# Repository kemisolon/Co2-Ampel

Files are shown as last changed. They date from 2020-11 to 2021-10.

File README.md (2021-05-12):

# Co2-Ampel
GitHub Logo

## ZTL (Zentrum für Technikkultur Landau) 
*** 

## Hardware:
1x Arduino Nano
5x WS2812B
1x SCD30

## Grenzwerte für die Co2-Ampel
grün  400-700ppm
gelb  700-1000ppm
rot   1000-2000ppm
rot-blinkend >2000ppm

## Gehäuse
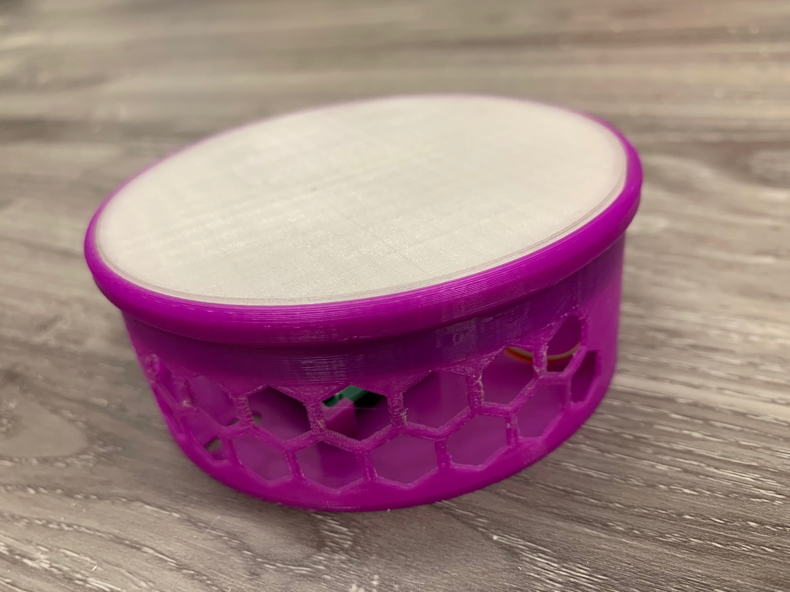
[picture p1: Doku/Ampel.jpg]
Die Ampel

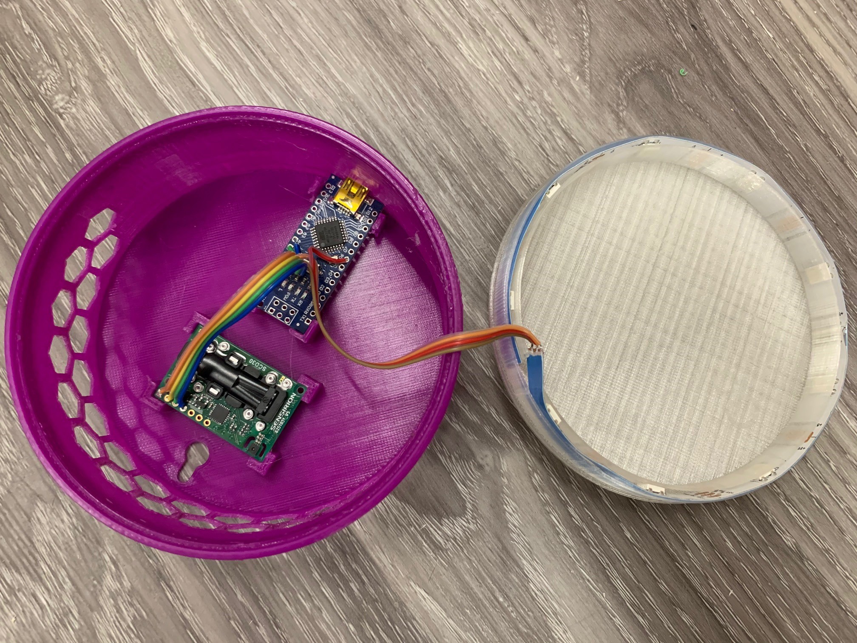
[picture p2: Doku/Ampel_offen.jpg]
Die Ampel offen


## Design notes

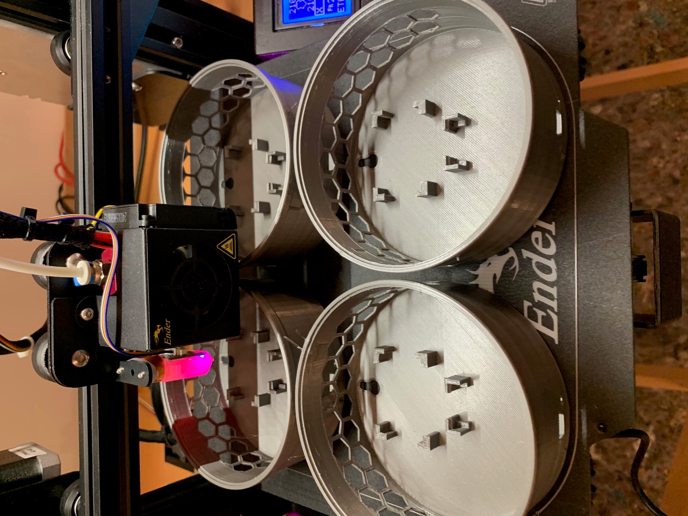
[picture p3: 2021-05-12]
Doku/druck.jpg

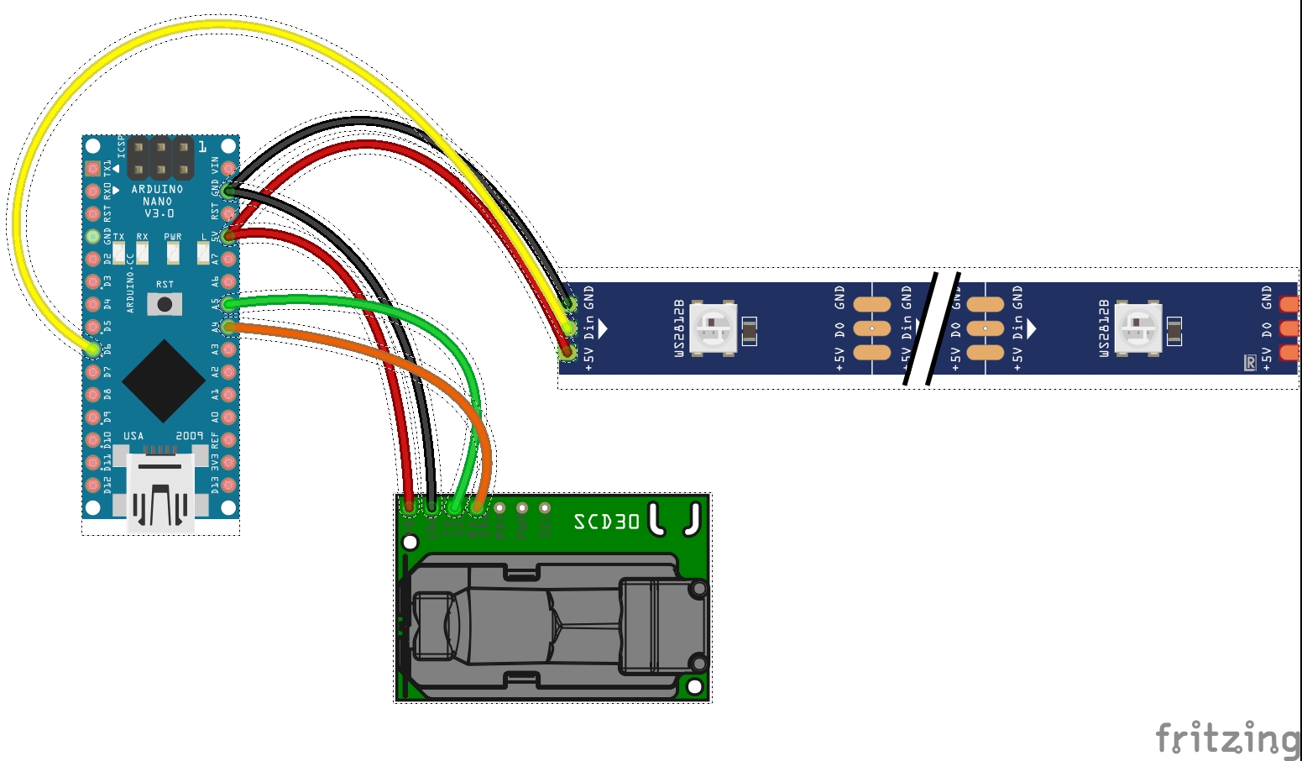
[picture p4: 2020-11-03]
Schaltplan/Schaltplan_Steckplatine.jpg

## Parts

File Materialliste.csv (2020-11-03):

Name | Quelle | Anzahl | Link
Arduino Nano | Amazon | 1/3 | https://www.amazon.de/AZDelivery-Atmega328-gratis-Arduino-kompatibel/dp/B078SBBST6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
CO2-Sensor SCD30 | Mouser | 1/100 | https://www.mouser.de/ProductDetail/403-SCD30SAMPLEEXT
LED WS2812B | Amazon | 1/100 | https://www.amazon.de/CHINLY-adressierbaren-LED-Streifen-Traumfarbe-Wasserdichte/dp/B07TKHMMZ2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
510 Ohm Widerstand | Reichelt | 1 | https://www.reichelt.de/widerstand-metallschicht-510-ohm-0207-0-6-w-1--metall-510-p11862.html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
MINI-USB-Kabel 2m Länge | Amazon | 1 | https://www.amazon.de/Premium-Cord-Kabel-B-Mini-5pins/dp/B00I97P5NI?__mk_de_DE=%C3%85M%C3%85%C5%BD%C3%95%C3%91
USB-Netzeil | Amazon | 1/100 | https://www.amazon.de/dp/B088NH9M6D
Filament Dunkelgrau metallic | Amazon | 1 | https://smile.amazon.de/gp/product/B07HDC3ZHF/ref=ppx_yo_dt_b_asin_title_o00_s00?ie=UTF8&th=1
Filament Durchsichtig | Amazon | 1 | https://smile.amazon.de/gp/product/B07H8MCNHY/ref=ppx_yo_dt_b_asin_title_o00_s00?ie=UTF8&th=1

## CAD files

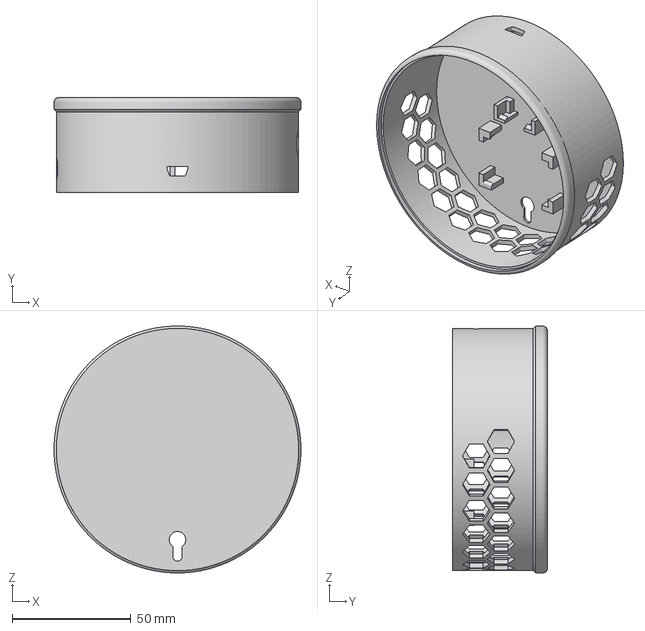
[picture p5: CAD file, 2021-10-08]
Gehäuse/Boden.3mf
104.0 x 40.0 x 104.0 mm

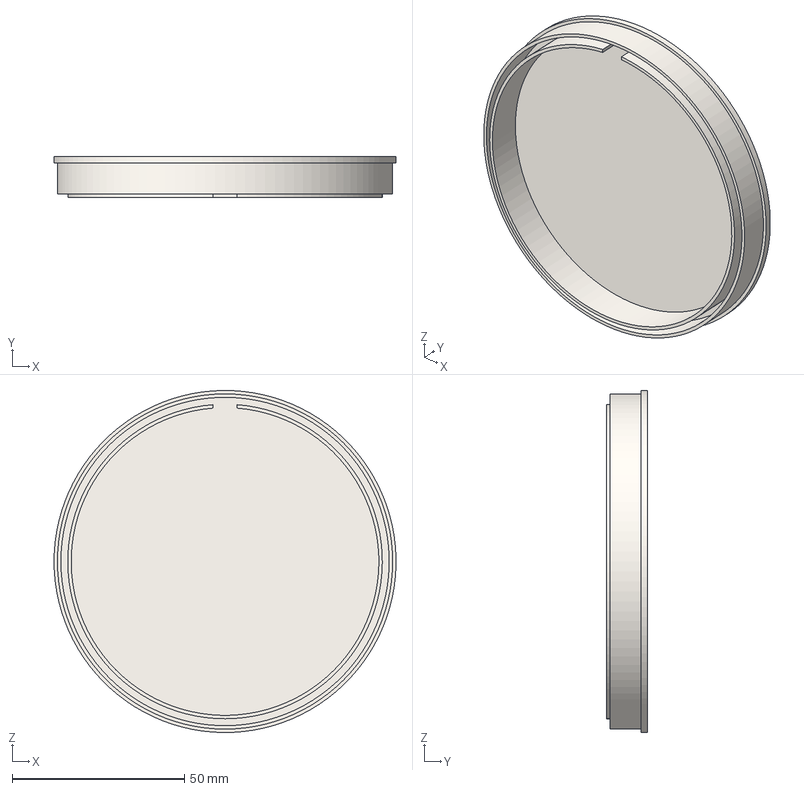
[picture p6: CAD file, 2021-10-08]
Gehäuse/Deckel.3mf
99.4 x 12.0 x 99.4 mm

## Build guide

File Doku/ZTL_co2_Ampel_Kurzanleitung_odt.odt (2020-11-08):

ZTL.co2.ampel

www.ztl.space - Kurzanleitung

1. Entstehung  ZTL steht für Zentrum für Technikkultur Landau e. V. – wir sind ein junger Verein mit technikbegeisterten Menschen, die gerne eigene Projekte umsetzen und sich hierbei gegenseitig unterstützen. Gerade errichten wir in Landau in der Nähe Media-Markt einen MAKERSPACE (offene Werkstatt) – neugierig? Komm vorbei!

Und mit Covid-19 kam die Idee eine CO2-Ampel zu bauen. Sie misst alle zwei Sekunden den CO2-Gehalt der Luft in ppm = parts per million. Ist die Luftqualität im Raum „schlecht“, signalisiert die CO2-Ampel anhand ihrer Farbe, dass jetzt bald mal gelüftet werden soll.

Gebaut hatten wir die Ampel eigentlich für unsere Vereinsräume und damit der Coronavirus nicht durch die Aerosole übertragen wird - denn an frischer Luft ist Corona fast kein Problem – davon sind die meisten Forscher überzeugt.

Und so kam die Idee mit dem befreundeten Technologie-Netzwerk Südpfalz e. V. das Projekt auf breite Schulter zu stellen und dieses auch Schulen und anderen Einrichtungen zur Verfügung zu stellen. Die CO2-Ampel wurde von unseren Vereinsmitgliedern ehrenamtlich selbst zusammengebaut und programmiert. Das Gehäuse kommt übrigens aus einem 3D-Drucker!

2. Inbetriebnahme  Es muss lediglich das Kabel angeschlossen werden und das Netzteil in die Steckdose gesteckt werden. Am besten stelle die CO2-Ampel an einen freien Ort (z. B. Schreibtisch), oder hänge sie an die Wand – jedoch nicht in die Nähe der Fenster.  Ist der Strom angeschlossen: Beim ersten Mal kann bis zu fünf Minuten dauern, bis der Sensor die Luftqualität messen kann. Solange sieht man entweder Regenbogen-Farben oder pinkfarbene LEDs, die nacheinander anfangen zu leuchten.

Ist die CO2-Ampel betriebsbereit, leuchten alle LEDs dauerhaft in den Farben rot/gelb/grün – wie eine Ampel eben

3. Statusfarben und -bedeutung  Alle zwei Sekunden wird der CO2-Gehalt der Luft in ppm gemessen. PPM steht für parts-per-million, also Teile pro Million.  Das Umweltbundesamt hatte bereits im Jahr 2008 Empfehlungen für Grenzwerte festgelegt, die wir in unsere CO2-Ampel übernommen hatten.  Quelle: https://www.umweltbundesamt.de/sites/default/files/medien/pdfs/kohlendioxid_2008.pdf  GRÜN = bis 700 ppm GELB = bis 1.000 ppm ROT = bis 2.000 ppm ROT blinkend = über 2.000 ppm  Bei der Farbe rot bzw. rot-blinkend wäre es dann wirklich an der Zeit zu lüften!
4. Fehlersuche  a) die CO2-Ampel tut gar nichts  Bitte prüfe, ob das Kabel richtig in die CO2-Ampel und in das Netzteil eingesteckt sind. Bitte schließe keine weiteren Geräte an dem USB-Netzteil an, wie Handy o.ä. Es könnte nämlich sein, dass der Strom für die CO2-Messung dann nicht ausreicht.  b) es werden nacheinander pinkfarbene LEDs im Uhrzeigersinn angezeigt  Der eingebaute CO2-Sensor kalibriert sich gerade, dies kann bis zu fünf Minuten dauern. Einfach abwarten

c) die CO2-Ampel leuchtet pink dauerhaft

Dann liegt ein Verbindungsproblem zwischen CO2-Sensor und der restlichen Technik vor. Hier kann Dir nur das ZTL helfen, siehe Punkt 5. In der Anleitung.

5. Support? Mitmachen!  Du möchtest in unserem Verein mitmachen? Oder hast eine Frage zu unserem Projekt? Dann komm melde Dich einfach in unserem Chat an unter  https://chat.ztl.space  Wir freuen uns auf Dich!

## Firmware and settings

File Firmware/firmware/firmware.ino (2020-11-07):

/*
  ZTL - Ampel - Version 1.0
  http://ztl.space
*/

#include <Arduino.h>
#include <Wire.h>
#include <Adafruit_NeoPixel.h>
#include "SparkFun_SCD30_Arduino_Library.h" //Click here to get the library: http://librarymanager/All#SparkFun_SCD30
#define PIN         6
#define NUMPIXELS   17 // oder 9 oder 17 LEDs
SCD30 airSensor;
Adafruit_NeoPixel pixels(NUMPIXELS, PIN, NEO_GRB + NEO_KHZ800);

// für den loop without delay

unsigned long previousMillis = 0; // Zeitpunkt an dem zuletzt geschalten wurde
const long interval = 2000;       // Länge der Pause in ms, hier 2 sek.
int startPixel = 0;               // erster Pixel für initSequenz
int ppm = 0;                      // 0 = ppm nicht gesetzt

//
// SETUP

void setup() {

  Serial.begin(115200);

  // Sensor Init...

  Wire.begin();
  if (airSensor.begin() == false) {
    Serial.println("Air sensor not detected. Please check wiring. Freezing...");
    pixels.begin();
    pixels.setBrightness(150);
    setColor(234, 10, 142); // pink dauerhaft, wenn Sensor nicht erkannt.
    while (1);
  }
  else
  {
    Serial.println("Air sensor detected!");
  }

  airSensor.setAutoSelfCalibration(false); // no auto calibration
  airSensor.setMeasurementInterval(2);     // CO2-Messung alle 5 s

  Serial.println("ZTL - Zentrum fuer Technikkultur Landau");
  Serial.println("http://ztl.space");
  Serial.println("Firmware Version 1.0");

  // Starte mit Regenbogen...

  pixels.begin();
  pixels.setBrightness(255);
  rainbow(10); // Init Party Mode :-)
  setColor(0, 0, 0); // schalte alle LEDs aus

  Serial.println("Initialisierung abgeschlossen.");
}

//
// Funktion SETCOLOUR zum Setzen der LED-Farben auf allen LEDs

void setColor(int r, int g, int b ) {
  for (int i = 0; i < NUMPIXELS; i++) {
    pixels.setPixelColor(i, pixels.Color(r, g, b));
  }
  pixels.show();
}

//
// Funktion BLINKRED zum roten Blinken aller LEDs

void blinkRed(long freq)
{
  static unsigned long previousMillis = 0;
  static bool ledState;
  unsigned long currentMillis = millis();

  if ((ledState == HIGH) && (currentMillis - previousMillis >= freq)) {
    ledState = LOW;
    previousMillis = currentMillis;
    setColor(0, 0, 0);
  }
  else if ((ledState == LOW) && (currentMillis - previousMillis >= freq)) {
    ledState = HIGH;  // turn it on
    previousMillis = currentMillis;
    setColor(255, 0, 0);
  }
}

//
// Funktion RAINBOW für den Regenbogen-LED-Effekt am Anfang

void rainbow(int wait) {
  for (long firstPixelHue = 0; firstPixelHue < 5 * 65536; firstPixelHue += 256) {
    for (int i = 0; i < pixels.numPixels(); i++) { // For each pixel in pixels...
      int pixelHue = firstPixelHue + (i * 65536L / pixels.numPixels());
      pixels.setPixelColor(i, pixels.gamma32(pixels.ColorHSV(pixelHue)));
    }
    pixels.show(); // Update pixels with new contents
    delay(wait);  // Pause for a moment
  }
}

//
// LOS GEHTS
//

void loop() {

  // Prüfe, ob Daten vom Sensor vorhanden sind

  if (airSensor.dataAvailable()) {
    ppm = airSensor.getCO2();
    Serial.print("co2(ppm):");
    Serial.print(ppm);

    Serial.print(" temp(C):");
    Serial.print(airSensor.getTemperature(), 1);

    Serial.print(" humidity(%):");
    Serial.print(airSensor.getHumidity(), 1);

    Serial.println();
  }


  // Loop without delay

  unsigned long currentMillis = millis(); // Aktuelle Zeit wird in currentMillis gespeichert
  if (currentMillis - previousMillis >= interval)
  {
    previousMillis = currentMillis; // Zeitpunkt der letzten Ausfuehrung wird festgehalten

    // Alle 2 Sekunden...

    if ( ppm  <  1 ) // keine Daten vorhanden, LED Punkte leuchten nacheinander
    {
      pixels.setBrightness(255);
      pixels.setPixelColor(startPixel, pixels.Color(234, 10, 142));
      pixels.show();
      if ( startPixel < NUMPIXELS ) {
        startPixel++;
      }
      else {
        startPixel = 0;
        setColor(0, 0, 0);
        pixels.setPixelColor(startPixel, pixels.Color(234, 10, 142));
      }
      Serial.print("Status: no data - waiting for sensor-init - this takes up to 5 min...");
      Serial.println();
    }
    else if ( ppm  <  1000 ) // 0 ...1000 PPM Grün
    {
      setColor(0, 255, 0);
      Serial.print("Status: green");
      Serial.println();
    }
    else if ( ppm  <  1400 ) // 1001 ...1400 PPM Gelb
    {
      setColor(255, 215, 0);
      Serial.print("Status: yellow");
      Serial.println();
    }
    else if ( ppm  <  2000 ) // 1401 ...2000 PPM Rot
    {
      setColor(255, 0, 0);
      Serial.print("Status: red");
      Serial.println();
    }
    else // > 2000 PPM rot blinkend
    {
      blinkRed(500);
      Serial.print("Status: blink-red");
      Serial.println();
    }
  }
}

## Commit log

2020-10-31 Code für PlatformIO portiert und Code Styling angepasst
2020-10-31 Materialliste hinzugefügt
    [Materialliste.csv]
2020-10-31 Fusion Datei hinzugefügt
    [Boden.stl, Co2_Ampel_ZTL.f3d, LED-Halter.stl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]
2020-10-31 .DS_Store gelöscht und zu gitignore hinzugefügt
2020-10-31 Update Materialliste.csv
    Moser-Price from netto to brutto
    [Materialliste.csv]
2020-10-31 verbesserte version vom Gehäuse
    [Co2_Ampel_ZTL v19.f3d]
2020-10-31 Kabelhalter hinzugeügt
    [Boden.stl, Kabelnupsi.stl, Lampe.stl]
2020-10-31 neuer Boden
    [Co2_Ampel_ZTL.f3d]
2020-10-31 neue STLs
    [Boden.stl, Kabelnupsi.stl]
2020-11-02 V2 STL
    [Boden.stl, Deckel.stl]
2020-11-03 Fillament Links hinzugefügt
    [Materialliste.csv]
2020-11-03 Boden geändert
    [Boden.stl]
2020-11-03 Schaltplan hinzugefügt
    [Schaltplan.fzz]
2020-11-04 Bilnken verbessert
    [Schaltplan.fzz]
2020-11-07 Kommentare und Farben angepasst
2021-05-12 Bilder der Ampel hinzugefügt
    Bilder für die Doku
2021-05-12 Bilder hinzugefügt
    Bilder der Ampel hinzugefügt
2021-10-08 Add files via upload
    Besseres Gehäuse design
    [Boden.3mf, Deckel.3mf]
